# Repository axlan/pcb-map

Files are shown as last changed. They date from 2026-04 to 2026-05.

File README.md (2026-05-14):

# PCB Map Display

This project is two related parts. First is the PCB map itself manufactured by [PCBWay](https://www.pcbway.com/). This is a PCB art piece that combines a map of the East Bay of California with an LED matrix display. The second part is the software to control the display.

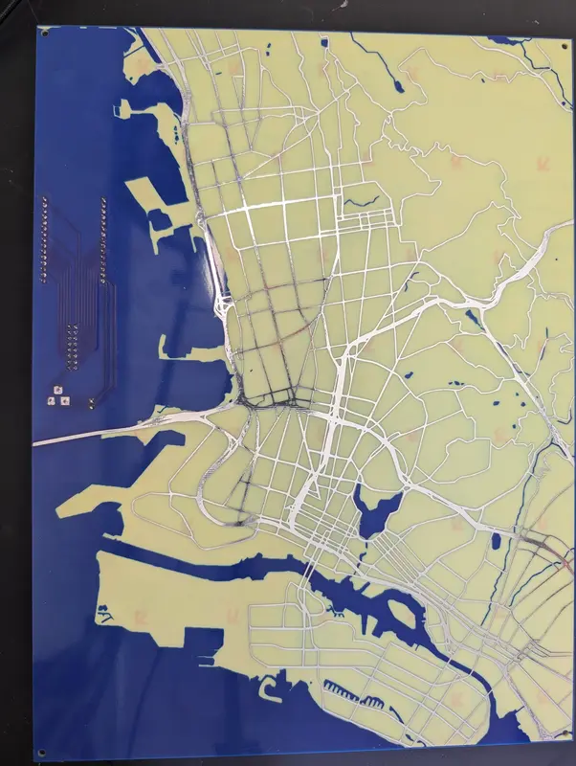
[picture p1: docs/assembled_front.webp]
Display front


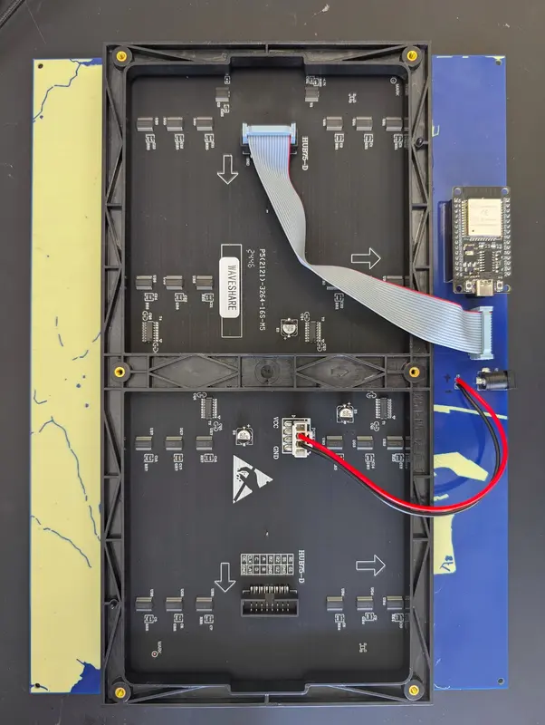
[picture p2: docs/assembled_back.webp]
Display back


The software is designed to be a fairly flexible controller for a matrix display, and the whole project could easily be used with a map printed on paper instead of a custom PCB.

<!-- <video src="docs/demo.mp4" autoplay loop muted playsinline></video> -->
<video src="https://github.com/user-attachments/assets/1058f474-8182-4159-85aa-21de5fce3b74" autoplay loop muted playsinline></video>

See <https://www.robopenguins.com/pcb-map/> for the design process.

---

## PCB Design Files

The design files can be found in `design/`.

The full design is in `design/map_board.kicad_pcb`, while the schematic for the ESP32 connected the the LED panel was designed in `design/wiring_project/map_lights.kicad_pro`

I came up with this project in response to an offer from [PCBWay](https://www.pcbway.com/) to manufacture a board for free in exchange for writing about the experience. The process of submitting the design files was straightforward, and I especially appreciated that their preview system showed the selected solder mask and surface finish colors. The design was flagged for manual review, and I had to confirm that the strange mostly-artistic board layout was intentional. This was entirely reasonable for a PCB that was deliberately designed to be mostly non-functional.

---

## Firmware

The firmware is located in the `firmware/` directory and is built using PlatformIO.

### Supported Matrix Display

The matrix display that this project was tested with is the:
[Waveshare RGB Full-Color LED Matrix Panel, 5mm Pitch, 64×32 Pixels](https://www.amazon.com/dp/B0CLV5MHPX)

It worked with the `ESP32 HUB75 LED MATRIX PANEL DMA Display` library out of the box, only needing to modify the `mxconfig.clkphase = false`.

My display was labeled as `P5(2121)-3264-16S-M5` (32x64 1/16 scan) and used the `RUC7258D`, `SM16208SJ`, and `MW245BC` control chips.

### Building and Uploading
To upload the firmware to your ESP32, use the provided helper script:
```bash
./scripts/upload_firmware.sh
```
This script uses PlatformIO to build the project and upload it to `pcb-map.local` (once the device is on your network).

### Initial WiFi Setup
If the device has no saved WiFi credentials, it will start an Access Point named **pcb-map-ap**. Connect to this AP with your phone or computer to configure your local WiFi settings via the captive portal.

### OTA Updates
The firmware supports Over-The-Air updates. Once configured on your network, you can re-flash the device wirelessly using PlatformIO's OTA functionality.

---

## Simulator

The simulator allows you to run the pcb-map logic on your desktop. It renders the LED matrix using SFML and connects to an MQTT broker to receive commands exactly like the hardware would.

### Building the Simulator
The simulator requires SFML, Paho MQTT C++, and OpenSSL. It uses CMake for building:

```bash
cd firmware/simulation
mkdir build && cd build
cmake ..
make
./matrix_sim
```
By default, it attempts to connect to a local MQTT broker at `tcp://localhost:1883`.

---

## Python Tools

The project includes a suite of Python scripts located in the `python/` directory to manage the device and feed it data.

### Environment Setup
Use uv to manage the Python environment:
```bash
uv --directory=python sync
source python/.venv/bin/activate
```

Install shell tab completion for the commands:
```bash
control-server --install-completion 
device-setup --install-completion 
```

### Configuration
Set up your environment variables (usually via a script like `pcb_map_args.sh`):
```bash
export MQTT_HOSTNAME="your-broker-address"
export MQTT_USE_TLS=1
export MQTT_USERNAME="user"
export MQTT_PASSWORD="pass"
# Used to query the Google Maps API for route information
export GOOGLE_MAPS_API_KEY="your-api-key"
# Used to set specific colors for people when using shared location display
export USER_COLORS_FILE="$HOME/user_colors.json"
```

#### user_colors.json
Define specific colors for people when using shared location display. When specified, only people in this configuration will be displayed.:
```json
{
    "me": [0, 255, 0],
    "Joe Smith": [0, 0, 255],
    "Mary Sue": [255, 0, 0]
}
```

### Key Commands

#### Device Setup (`device-setup`)
- `find-devices`: Discovers the board via mDNS, MQTT, or by scanning for the setup AP.
- `setup-mqtt`: Configures the MQTT broker credentials on the device via a local UDP broadcast.
- `clear-wifi-creds`: Resets the WiFi settings on the hardware.

Here's a rundown of how device configuration works:

Configuration state machine

The `find-devices` command gives the context for what state the device is in.

#### Control Server (`control-server`)
- `display-shared-locations`: Fetches shared Google locations and plots them on the matrix.
- `set-background-image [path]`: Uploads and displays a 64x32 RGB image as the map background.
- `simulate-route --start "Home" --dest "Work"`: Calculates a route and animates it on the display.
- `set-brightness [0-100]`: Adjusts the LED intensity.
- `clear-display`: Clears all active sprites and hides the background.
- `lat-long-to-xy`: A utility to check where a coordinate falls on the matrix grid.

---

## Development Utilities

**Formatting Code** (C++):
```bash
clang-format -style=Google -i firmware/src/*
```

## TODO
 - Improve fetching Google map creds for location sharing from a remote browser
 - Make location share able to run as a server more robustly
 - Scrape Google calendar for events with locations for drawing routes
 - Separate MQTT client and config into reusable library
 - Add MQTT errors stat

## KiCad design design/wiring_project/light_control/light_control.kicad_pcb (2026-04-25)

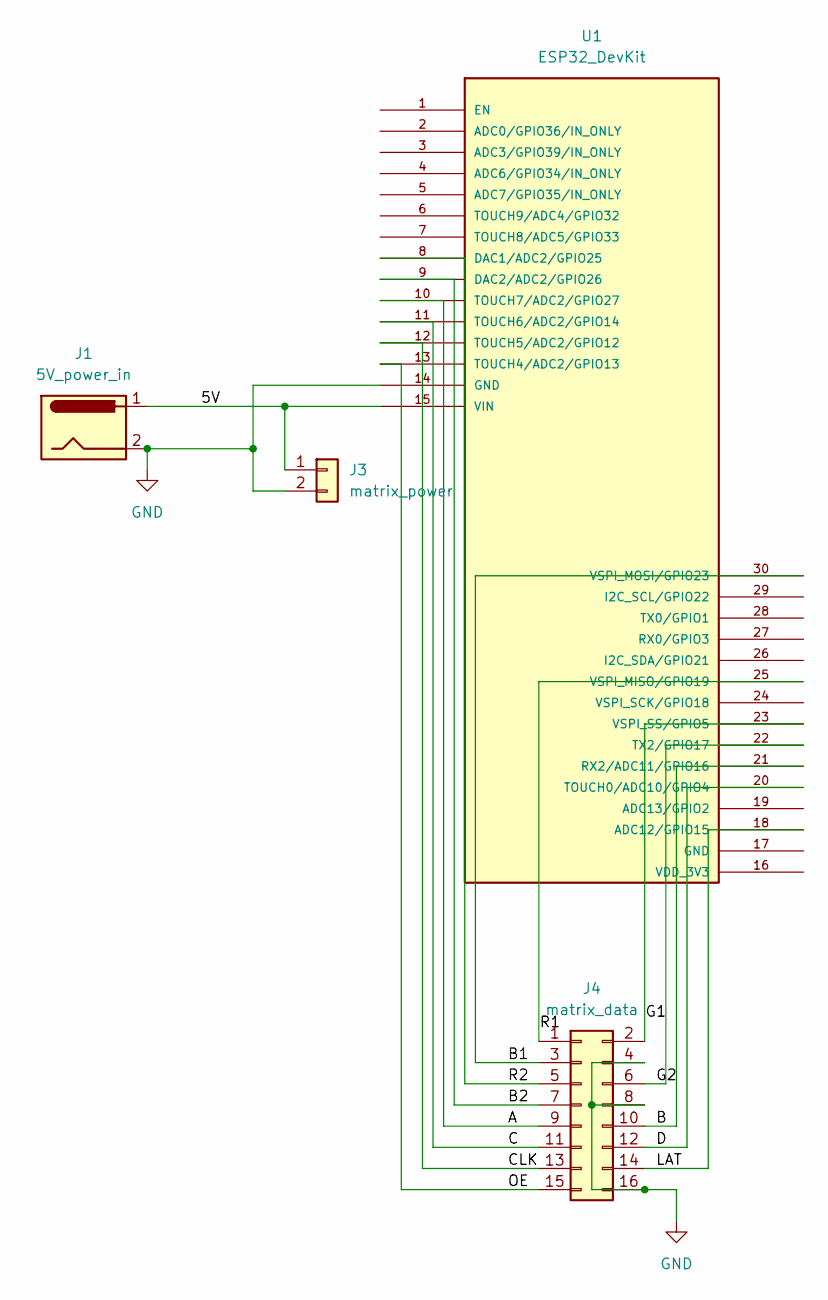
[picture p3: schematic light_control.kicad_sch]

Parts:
J1: 5V_power_in; BarrelJack_Horizontal
J3: matrix_power; PinHeader_1x02_P2.54mm_Vertical
J4: matrix_data; PinHeader_2x08_P2.54mm_Vertical
U1: ESP32_DevKit; esp32_devkit

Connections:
/5V: J1.1, J3.1, U1.15 (VIN)
/A: J4.9, U1.10 (TOUCH7/ADC2/GPIO27)
/B: J4.10, U1.21 (RX2/ADC11/GPIO16)
/B1: J4.3, U1.30 (VSPI_MOSI/GPIO23)
/B2: J4.7, U1.9 (DAC2/ADC2/GPIO26)
/C: J4.11, U1.11 (TOUCH6/ADC2/GPIO14)
/CLK: J4.13, U1.12 (TOUCH5/ADC2/GPIO12)
/D: J4.12, U1.20 (TOUCH0/ADC10/GPIO4)
/G1: J4.2, U1.23 (VSPI_SS/GPIO5)
/G2: J4.6, U1.22 (TX2/GPIO17)
/LAT: J4.14, U1.18 (ADC12/GPIO15)
/OE: J4.15, U1.13 (TOUCH4/ADC2/GPIO13)
/R1: J4.1, U1.25 (VSPI_MISO/GPIO19)
/R2: J4.5, U1.8 (DAC1/ADC2/GPIO25)
GND: J1.2, J3.2, J4.4, J4.8, J4.16, U1.14 (GND)

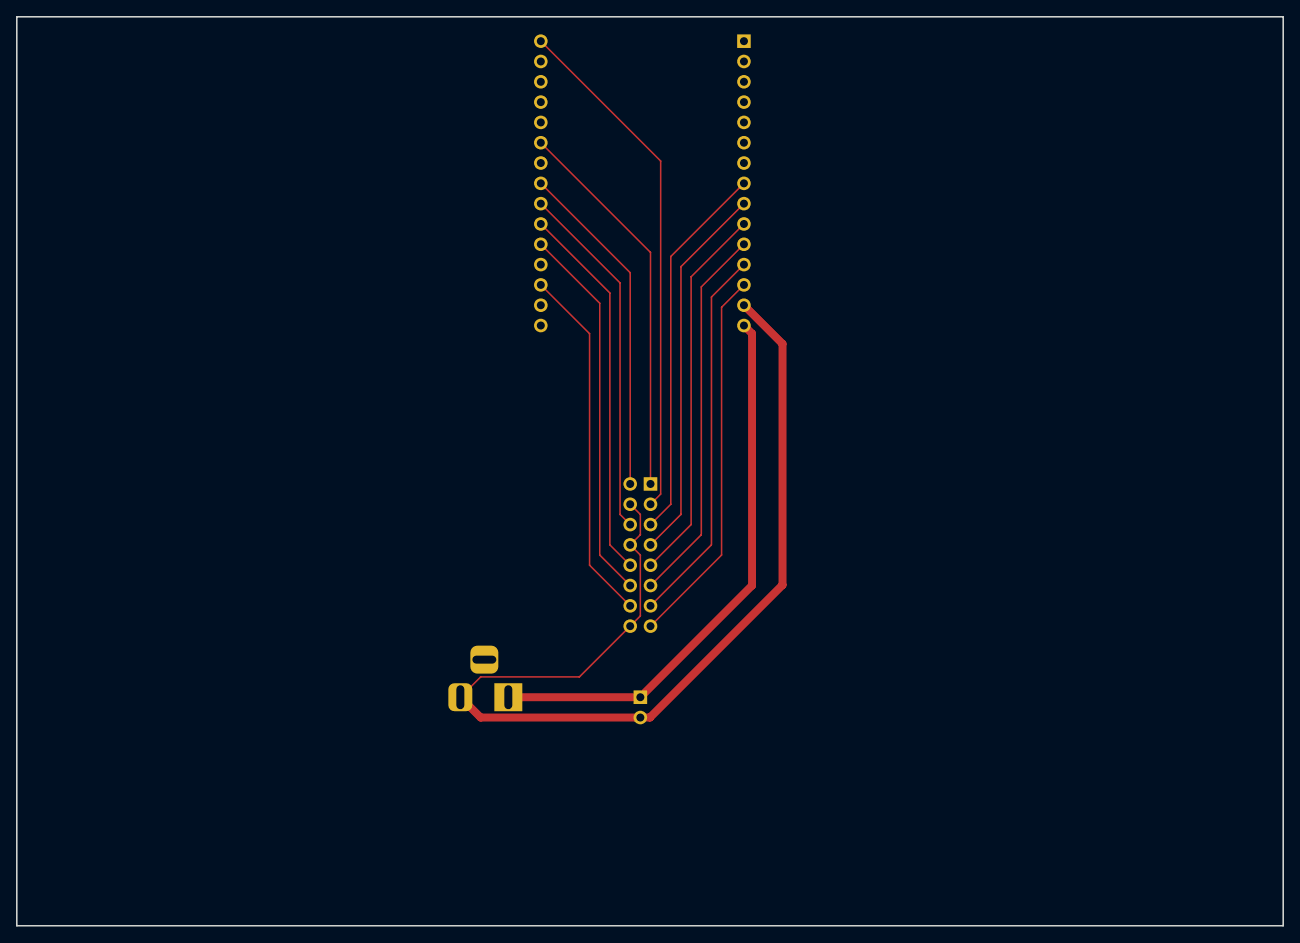
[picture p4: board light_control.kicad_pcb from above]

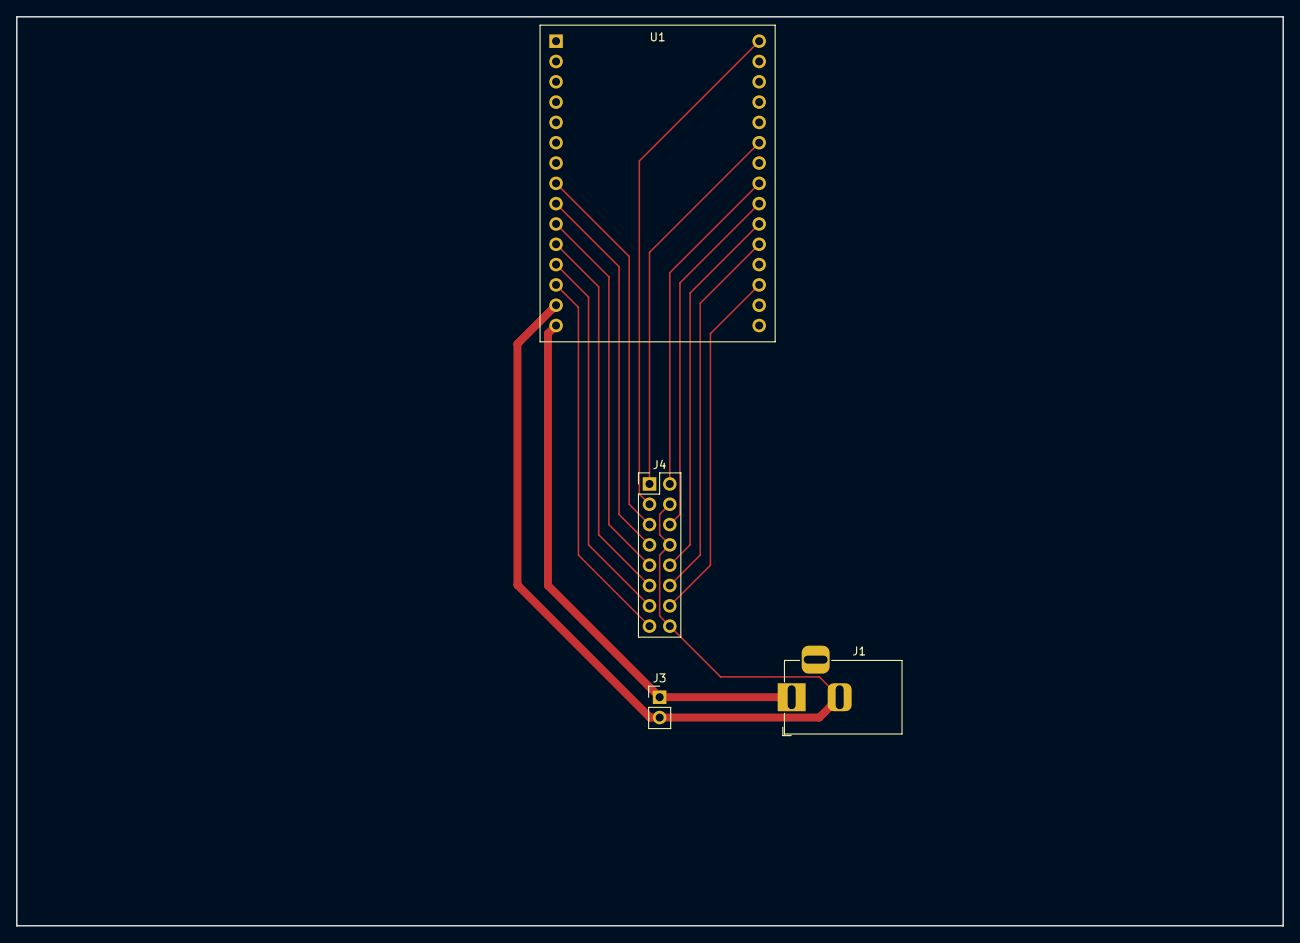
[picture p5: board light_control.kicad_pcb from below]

Board: 2 copper layers, 158.4 x 113.7 mm, 4 parts (4 on the bottom side), 15 nets.

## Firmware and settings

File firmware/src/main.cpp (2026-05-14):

// pio run -t upload --upload-port pcb-map.local

#include <Arduino.h>
#include <ArduinoOTA.h>
#include <ESPmDNS.h>
#include <WiFiManager.h>

#include "esp_log.h"

static const char* TAG = "main";

#include "matrix_interface.h"
#include "matrix_sprite_ctrl.h"
#include "mqtt_client.h"
#include "mqtt_config.h"

static constexpr const char* MDNS_HOSTNAME = "pcb-map";

static constexpr const char* ADHOC_AP = "pcb-map-ap";

// Topic constants
static constexpr const char* MQTT_CLIENT_NAME = "pcb-map";
static constexpr const char* MQTT_CLEAR_WIFI_TOPIC = "pcb-map/clear_wifi";
static constexpr const char* MQTT_PING_TOPIC = "pcb-map/ping";
static constexpr const char* MQTT_PONG_TOPIC = "pcb-map/pong";
static constexpr const char* MQTT_STATS_TOPIC = "pcb-map/stats";

static const unsigned long STATS_PUBLISH_INTERVAL = 10000;  // 10 seconds
static const float ROLLING_AVG_ALPHA =
    0.1f;  // Exponential moving average factor

// Stats calculation state - Internal state for rolling averages and timing
struct StatsState {
  float loop_time_rolling_avg = 0.0f;
  unsigned long loop_cycle_start_time = 0;
  unsigned long last_stats_publish_time = 0;
  float loop_time_worst = 0.0f;
  uint32_t commands_handled = 0;
};

static StatsState current_stats;

// clang-format off
// Root CA Cert for *.s1.eu.hivemq.cloud (https://letsencrypt.org/certs/isrgrootx1.pem)
// #define MQTT_BROKER_CA_CERT "-----BEGIN CERTIFICATE-----\nMIIFazCCA1OgAwIBAgIRAIIQz7DSQONZRGPgu2OCiwAwDQYJKoZIhvcNAQELBQAw\nTzELMAkGA1UEBhMCVVMxKTAnBgNVBAoTIEludGVybmV0IFNlY3VyaXR5IFJlc2Vh\ncmNoIEdyb3VwMRUwEwYDVQQDEwxJU1JHIFJvb3QgWDEwHhcNMTUwNjA0MTEwNDM4\nWhcNMzUwNjA0MTEwNDM4WjBPMQswCQYDVQQGEwJVUzEpMCcGA1UEChMgSW50ZXJu\nZXQgU2VjdXJpdHkgUmVzZWFyY2ggR3JvdXAxFTATBgNVBAMTDElTUkcgUm9vdCBY\nMTCCAiIwDQYJKoZIhvcNAQEBBQADggIPADCCAgoCggIBAK3oJHP0FDfzm54rVygc\nh77ct984kIxuPOZXoHj3dcKi/vVqbvYATyjb3miGbESTtrFj/RQSa78f0uoxmyF+\n0TM8ukj13Xnfs7j/EvEhmkvBioZxaUpmZmyPfjxwv60pIgbz5MDmgK7iS4+3mX6U\nA5/TR5d8mUgjU+g4rk8Kb4Mu0UlXjIB0ttov0DiNewNwIRt18jA8+o+u3dpjq+sW\nT8KOEUt+zwvo/7V3LvSye0rgTBIlDHCNAymg4VMk7BPZ7hm/ELNKjD+Jo2FR3qyH\nB5T0Y3HsLuJvW5iB4YlcNHlsdu87kGJ55tukmi8mxdAQ4Q7e2RCOFvu396j3x+UC\nB5iPNgiV5+I3lg02dZ77DnKxHZu8A/lJBdiB3QW0KtZB6awBdpUKD9jf1b0SHzUv\nKBds0pjBqAlkd25HN7rOrFleaJ1/ctaJxQZBKT5ZPt0m9STJEadao0xAH0ahmbWn\nOlFuhjuefXKnEgV4We0+UXgVCwOPjdAvBbI+e0ocS3MFEvzG6uBQE3xDk3SzynTn\njh8BCNAw1FtxNrQHusEwMFxIt4I7mKZ9YIqioymCzLq9gwQbooMDQaHWBfEbwrbw\nqHyGO0aoSCqI3Haadr8faqU9GY/rOPNk3sgrDQoo//fb4hVC1CLQJ13hef4Y53CI\nrU7m2Ys6xt0nUW7/vGT1M0NPAgMBAAGjQjBAMA4GA1UdDwEB/wQEAwIBBjAPBgNV\nHRMBAf8EBTADAQH/MB0GA1UdDgQWBBR5tFnme7bl5AFzgAiIyBpY9umbbjANBgkq\nhkiG9w0BAQsFAAOCAgEAVR9YqbyyqFDQDLHYGmkgJykIrGF1XIpu+ILlaS/V9lZL\nubhzEFnTIZd+50xx+7LSYK05qAvqFyFWhfFQDlnrzuBZ6brJFe+GnY+EgPbk6ZGQ\n3BebYhtF8GaV0nxvwuo77x/Py9auJ/GpsMiu/X1+mvoiBOv/2X/qkSsisRcOj/KK\nNFtY2PwByVS5uCbMiogziUwthDyC3+6WVwW6LLv3xLfHTjuCvjHIInNzktHCgKQ5\nORAzI4JMPJ+GslWYHb4phowim57iaztXOoJwTdwJx4nLCgdNbOhdjsnvzqvHu7Ur\nTkXWStAmzOVyyghqpZXjFaH3pO3JLF+l+/+sKAIuvtd7u+Nxe5AW0wdeRlN8NwdC\njNPElpzVmbUq4JUagEiuTDkHzsxHpFKVK7q4+63SM1N95R1NbdWhscdCb+ZAJzVc\noyi3B43njTOQ5yOf+1CceWxG1bQVs5ZufpsMljq4Ui0/1lvh+wjChP4kqKOJ2qxq\n4RgqsahDYVvTH9w7jXbyLeiNdd8XM2w9U/t7y0Ff/9yi0GE44Za4rF2LN9d11TPA\nmRGunUHBcnWEvgJBQl9nJEiU0Zsnvgc/ubhPgXRR4Xq37Z0j4r7g1SgEEzwxA57d\nemyPxgcYxn/eR44/KJ4EBs+lVDR3veyJm+kXQ99b21/+jh5Xos1AnX5iItreGCc=\n-----END CERTIFICATE-----"
// clang-format on

static void HandleMQTTMessage(const char* topic, byte* payload,
                              unsigned int length);

MQTTClientManager mqtt_manager(
    MQTT_CLIENT_NAME,
    {MQTT_CLEAR_WIFI_TOPIC, MQTT_PING_TOPIC, MQTT_SPRITE_DELETE_TOPIC,
     MQTT_SPRITE_UPDATE_TOPIC, MQTT_SPRITES_CLEAR_TOPIC,
     MQTT_BACKGROUND_SET_ROW_TOPIC, MQTT_BACKGROUND_SHOW_TOPIC,
     MQTT_BACKGROUND_HIDE_TOPIC, MQTT_SET_BRIGHTNESS_TOPIC},
    HandleMQTTMessage, MQTTConfig{});

MatrixSpriteController sprite_ctrl;
MatrixInterface matrix_interface(&sprite_ctrl);

static void HandleMQTTMessage(const char* topic, byte* payload,
                              unsigned int length) {
  ESP_LOGI(TAG, "[MQTT] Message received on topic: %s", topic);

  if (strcmp(topic, MQTT_CLEAR_WIFI_TOPIC) == 0) {
    ESP_LOGI(TAG, "[MQTT] Clearing WiFi credentials and restarting...");

    // Clear saved WiFi credentials
    WiFiManager wm;
    wm.resetSettings();

    delay(1000);
    ESP.restart();
  } else if (strcmp(topic, MQTT_PING_TOPIC) == 0) {
    ESP_LOGI(TAG, "[MQTT] Responding to ping...");

    mqtt_manager.GetClient()->publish(MQTT_PONG_TOPIC, "pong");
  } else {
    matrix_interface.HandleMQTTMessage(topic, payload, length);
  }
  current_stats.commands_handled++;
}

void setupOTA() {
  ArduinoOTA.setHostname(MDNS_HOSTNAME);

  ArduinoOTA.onStart([]() {
    String type =
        (ArduinoOTA.getCommand() == U_FLASH) ? "sketch" : "filesystem";
    ESP_LOGI(TAG, "OTA Update starting: %s", type.c_str());
  });

  ArduinoOTA.onEnd([]() { ESP_LOGI(TAG, "OTA Update completed!"); });

  ArduinoOTA.onProgress([](unsigned int progress, unsigned int total) {
    ESP_LOGI(TAG, "OTA Progress: %u%%", (progress / (total / 100)));
  });

  ArduinoOTA.onError([](ota_error_t error) {
    if (error == OTA_AUTH_ERROR)
      ESP_LOGE(TAG, "OTA Error [%u]: Authentication failed", error);
    else if (error == OTA_BEGIN_ERROR)
      ESP_LOGE(TAG, "OTA Error [%u]: Begin failed", error);
    else if (error == OTA_CONNECT_ERROR)
      ESP_LOGE(TAG, "OTA Error [%u]: Connect failed", error);
    else if (error == OTA_RECEIVE_ERROR)
      ESP_LOGE(TAG, "OTA Error [%u]: Receive failed", error);
    else if (error == OTA_END_ERROR)
      ESP_LOGE(TAG, "OTA Error [%u]: End failed", error);
  });

  ArduinoOTA.begin();
}

void RunWifiManager() {
  // WiFiManager, Local initialization. Once its business is done, there is no
  // need to keep it around
  WiFiManager wm;

  MQTTConfig config;
  MQTTConfigManager::LoadMQTTConfig(&config);

  char port_str[6];
  snprintf(port_str, sizeof(port_str), "%u", config.port);

  WiFiManagerParameter custom_mqtt_host("host", "MQTT Host", config.host.c_str(),
                                        64);
  WiFiManagerParameter custom_mqtt_port("port", "MQTT Port", port_str, 6);
  WiFiManagerParameter custom_mqtt_user("user", "MQTT User",
                                        config.user_name.c_str(), 64);
  WiFiManagerParameter custom_mqtt_pass("pass", "MQTT Password",
                                        config.password.c_str(), 64);
  WiFiManagerParameter custom_mqtt_tls("tls", "Use TLS (1/0)",
                                       config.use_tls ? "1" : "0", 2);

  wm.addParameter(&custom_mqtt_host);
  wm.addParameter(&custom_mqtt_port);
  wm.addParameter(&custom_mqtt_user);
  wm.addParameter(&custom_mqtt_pass);
  wm.addParameter(&custom_mqtt_tls);

  // Automatically connect using saved credentials. If connection fails, it
  // starts an access point and enters a blocking loop awaiting configuration.
  bool connected = wm.autoConnect(ADHOC_AP);

  if (!connected) {
    ESP_LOGE(TAG, "Failed to connect");
    ESP.restart();
  }

  bool config_changed = false;

  if (config.host != custom_mqtt_host.getValue()) {
    config.host = custom_mqtt_host.getValue();
    config_changed = true;
  }
  uint16_t new_port = (uint16_t)atoi(custom_mqtt_port.getValue());
  if (config.port != new_port) {
    config.port = new_port;
    config_changed = true;
  }
  if (config.user_name != custom_mqtt_user.getValue()) {
    config.user_name = custom_mqtt_user.getValue();
    config_changed = true;
  }
  if (config.password != custom_mqtt_pass.getValue()) {
    config.password = custom_mqtt_pass.getValue();
    config_changed = true;
  }
  bool new_use_tls = (strcmp(custom_mqtt_tls.getValue(), "1") == 0);
  if (config.use_tls != new_use_tls) {
    config.use_tls = new_use_tls;
    config_changed = true;
  }

  if (config_changed) {
    ESP_LOGI(TAG, "Updating MQTT Config from WifiManager.");
    MQTTConfigManager::Set(config);
  }
}

void setup() {
  Serial.begin(115200);

  sprite_ctrl.Init();

  RunWifiManager();

#ifdef MQTT_BROKER_CA_CERT
  mqtt_manager.SetCACert(MQTT_BROKER_CA_CERT);
#endif

  MDNS.begin(MDNS_HOSTNAME);
  setupOTA();
  ESP_LOGI(TAG, "OTA Ready!");
  MQTTConfigManager::Begin(
      [&](const MQTTConfig& config) { mqtt_manager.OnConfigChange(config); });

  current_stats.last_stats_publish_time = millis();
  current_stats.loop_cycle_start_time = millis();

  // sprite_ctrl.AddSprite(SpritePtr(new PixelSprite("test",16,16,0xF800)));
}

void UpdateStats(float loop_time_ms) {
  // Update rolling average (exponential moving average)
  if (current_stats.loop_time_rolling_avg == 0.0f) {
    current_stats.loop_time_rolling_avg = loop_time_ms;
  } else {
    current_stats.loop_time_rolling_avg =
        (ROLLING_AVG_ALPHA * loop_time_ms) +
        ((1.0f - ROLLING_AVG_ALPHA) * current_stats.loop_time_rolling_avg);
  }

  // Update worst time
  if (loop_time_ms > current_stats.loop_time_worst) {
    current_stats.loop_time_worst = loop_time_ms;
  }

  // Update current stats
  auto uptime = millis() / 1000;
  auto heap_free = ESP.getFreeHeap();

  // Publish stats every 10 seconds
  if (millis() - current_stats.last_stats_publish_time >=
      STATS_PUBLISH_INTERVAL) {
    // Build JSON stats
    char json_buffer[256];
    snprintf(json_buffer, sizeof(json_buffer),
             "{\"uptime\":%lu,\"heap_free\":%u,\"loop_time_mean_ms\":%.2f,"
             "\"loop_time_worst_ms\":%.2f,\"commands_handled\":%u}",
             uptime, heap_free, current_stats.loop_time_rolling_avg,
             current_stats.loop_time_worst, current_stats.commands_handled);

    ESP_LOGI(TAG, "[Stats] %s", json_buffer);
    mqtt_manager.GetClient()->publish(MQTT_STATS_TOPIC, json_buffer);
    current_stats.loop_time_worst = 0;
    current_stats.last_stats_publish_time = millis();
  }
}

void loop() {
  unsigned long loop_start = millis();

  ArduinoOTA.handle();

  // Update MQTT client (handles connection, reconnection, and config updates)
  MQTTConfigManager::Update();
  mqtt_manager.Update();

  sprite_ctrl.Draw();

  // Calculate loop execution time
  unsigned long loop_end = millis();
  float loop_time_ms = static_cast<float>(loop_end - loop_start);
  UpdateStats(loop_time_ms);
}

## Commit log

2026-04-25 Tested MQTT config.
    [light_control.kicad_pcb, light_control.kicad_sch, map_board.kicad_pcb]
2026-05-06 Add LED pulse option, and some cleanup.
2026-05-06 Switch to using google maps for routing.
